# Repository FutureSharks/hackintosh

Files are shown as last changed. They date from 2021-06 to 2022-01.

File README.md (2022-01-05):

# My Hackintosh

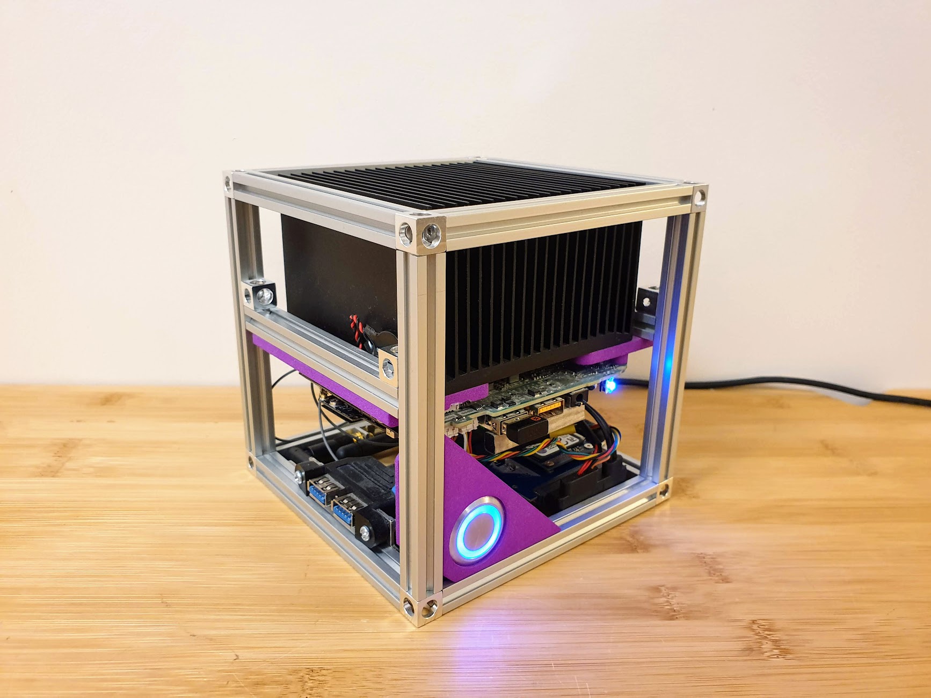
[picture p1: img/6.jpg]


My current build runs macOS Monterey 12.0.1, [OpenCore](https://dortania.github.io/OpenCore-Install-Guide/) 0.7.5 and is based on a fanless Intel [NUC8i5BEK](https://ark.intel.com/content/www/us/en/ark/products/126147/intel-nuc-kit-nuc8i5bek.html) with a [i5-8259U CPU](https://ark.intel.com/content/www/us/en/ark/products/135935/intel-core-i58259u-processor-6m-cache-up-to-3-80-ghz.html).

## What works, what does not

- ✅ GPU acceleration
- ✅ HDMI audio
- ✅ HDMI and USB-C video at 2560 x 1440 @ 60 Hz
- ✅ USB2 / USB3 / USB-C
- ✅ SATA storage
- ✅ WiFi/WLAN in M.2 slot
- ❔ Front panel audio: not tested
- ❔ SD card reader: not tested
- ❔ Other display resolutions: not tested
- ❌ Sleep/wake: Doesn't work
- ❌ Bluetooth: Unreliable (maybe antenna is inadequate)
- ❌ Built in WLAN/Bluetooth: It is [apparently possible but not perfect](https://github.com/OpenIntelWireless/itlwm)

## Hackintosh details

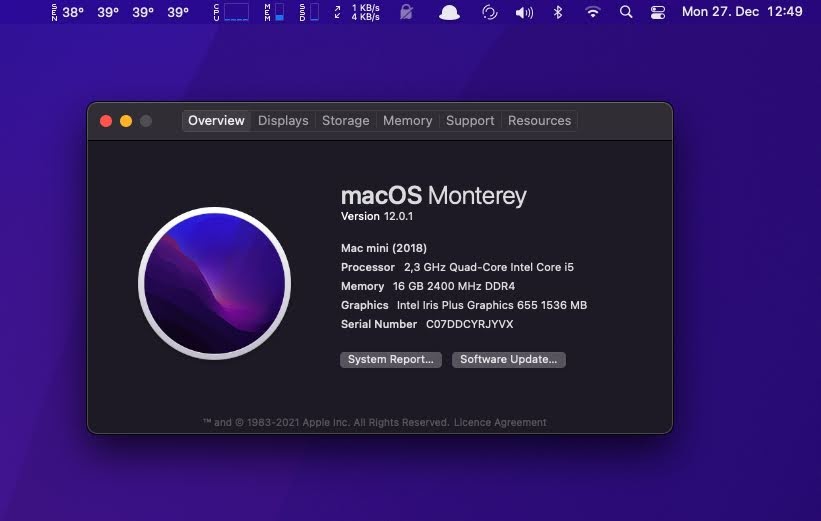
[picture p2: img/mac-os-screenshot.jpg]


Runs [OpenCore](https://dortania.github.io/OpenCore-Install-Guide/) 0.7.5:

- [config.plist](EFI/OC/config.plist)
- [EFI](EFI) directory

## Photos

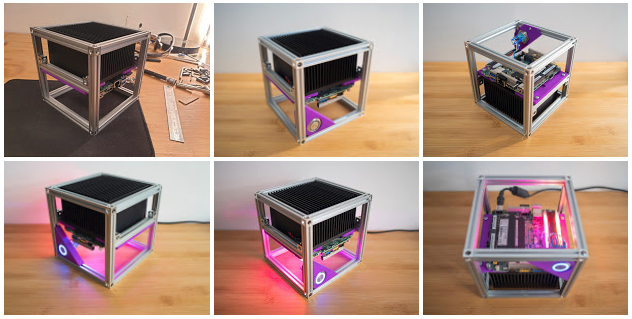
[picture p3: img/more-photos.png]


## Hardware

### Specs

- Intel Core i5-8259U CPU (built in)
- Intel Iris Plus Graphics 655 (built in)
- 16GB RAM F4-2400C16D-16G
- Kingston KC600 512GB mSATA SSD (with mSATA adapter)
- Broadcom BCM94360CD WiFi WLAN + Bluetooth 4.0 (with modified M.2 NGFF Adapter Card)
- Alpine AM4 Passive CPU cooler, required some machining to fit
- Makerbeam open case structure
- Custom 3D printed CPU mounting brackets
- Custom 3D printed power switch bracket

### Power consumption and temperatures

Power measured at wall, temperature measured from built in sensors.

| State | Power (watts) | CPU temp (°C) |
|---|---|---|
| Powered off | 0.5 | 0 |
| Booted OS, idle | 6-10 | 29 |
| Normal use with Chrome, AutoCAD, Spotify etc | 10-20 | 40-70 |
| Prime95 or stress | 52 | 90 |

### CAD files

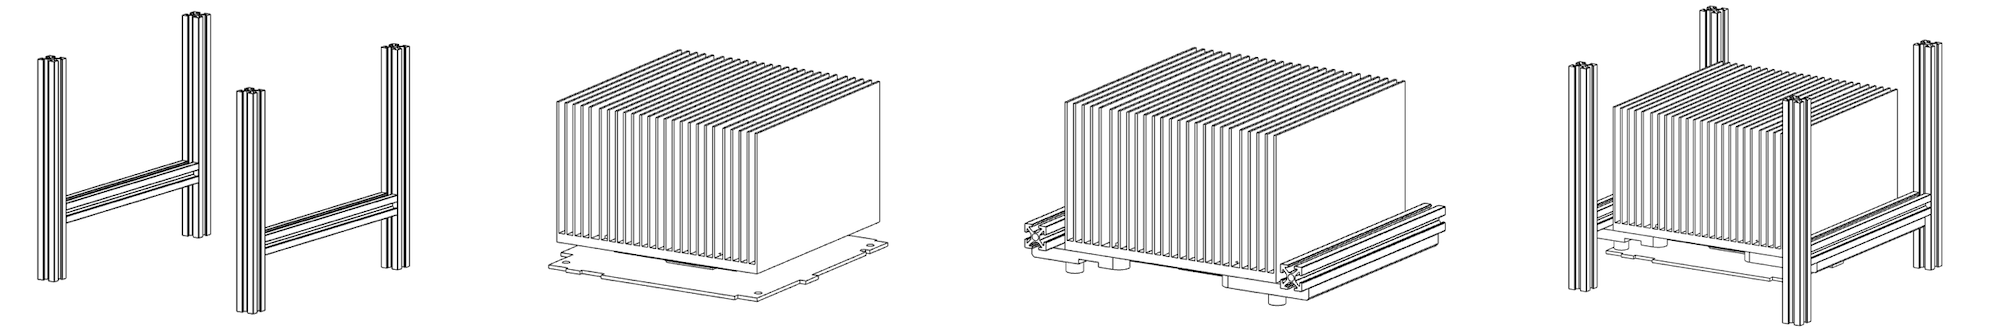
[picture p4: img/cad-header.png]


Fusion 360 project file, Heatsink bracket STL and Switch bracket STL files are in: [cad-files](cad-files)

## OpenCore setup process

Download OpenCore release and other required files:

```
# Save into separate directory
cd downloads

# Get Nucintosh release
wget https://github.com/zearp/Nucintosh/releases/download/v3.1/EFI_05112021.zip

# Get OpenCore release
wget https://github.com/acidanthera/OpenCorePkg/releases/download/0.7.5/OpenCore-0.7.5-RELEASE.zip

# Get others
wget https://github.com/acidanthera/OcBinaryData/raw/master/Drivers/HfsPlus.efi
wget https://github.com/acidanthera/VirtualSMC/releases/download/1.2.7/VirtualSMC-1.2.7-RELEASE.zip
wget https://github.com/acidanthera/Lilu/releases/download/1.5.7/Lilu-1.5.7-RELEASE.zip
wget https://github.com/acidanthera/WhateverGreen/releases/download/1.5.5/WhateverGreen-1.5.5-RELEASE.zip
wget https://github.com/acidanthera/AppleALC/releases/download/1.6.6/AppleALC-1.6.6-RELEASE.zip
wget https://github.com/acidanthera/IntelMausi/releases/download/1.0.7/IntelMausi-1.0.7-RELEASE.zip
wget https://github.com/acidanthera/BrcmPatchRAM/releases/download/2.6.1/BrcmPatchRAM-2.6.1-RELEASE.zip
wget https://github.com/acidanthera/NVMeFix/releases/download/1.0.9/NVMeFix-1.0.9-RELEASE.zip

# Get required SSDTs
wget https://github.com/dortania/Getting-Started-With-ACPI/raw/master/extra-files/compiled/SSDT-AWAC.aml
wget https://github.com/dortania/Getting-Started-With-ACPI/raw/master/extra-files/compiled/SSDT-PMC.aml
```

Extract all zip files in `downloads`.

Now build our initial EFI directory based on OpenCore release, [Nucintosh](https://github.com/zearp/Nucintosh) SSDTs and `config.plist`:

```
rm -rf EFI
cp -a downloads/OpenCore-0.7.5-RELEASE/X64/EFI .
```

Clean it up:

```
cp EFI/OC/Drivers/OpenRuntime.efi .
rm -f EFI/OC/Drivers/*
mv OpenRuntime.efi EFI/OC/Drivers/
cp EFI/OC/Tools/OpenShell.efi .
rm -f EFI/OC/Tools/*
mv OpenShell.efi EFI/OC/Tools/
```

Add other required files and kexts:

```
cp downloads/HfsPlus.efi EFI/OC/Drivers/
cp -a downloads/Lilu-1.5.7-RELEASE/Lilu.kext EFI/OC/Kexts/
cp -a downloads/VirtualSMC-1.2.7-RELEASE/Kexts/SMCProcessor.kext EFI/OC/Kexts/
cp -a downloads/VirtualSMC-1.2.7-RELEASE/Kexts/SMCSuperIO.kext EFI/OC/Kexts/
cp -a downloads/VirtualSMC-1.2.7-RELEASE/Kexts/VirtualSMC.kext EFI/OC/Kexts/
cp -a downloads/WhateverGreen-1.5.5-RELEASE/WhateverGreen.kext EFI/OC/Kexts/
cp -a downloads/AppleALC-1.6.6-RELEASE/AppleALC.kext EFI/OC/Kexts/
cp -a downloads/IntelMausi-1.0.7-RELEASE/IntelMausi.kext EFI/OC/Kexts/
cp -a downloads/BrcmPatchRAM-2.6.1-RELEASE/BlueToolFixup.kext EFI/OC/Kexts/
```

Get `config.plist`, SSDTs and USBPorts kext from [Nucintosh](https://github.com/zearp/Nucintosh) release:

```
cp downloads/EFI/OC/config.plist EFI/OC/config.plist
cp downloads/EFI/OC/ACPI/*.aml EFI/OC/ACPI/
cp -a downloads/EFI/OC/Kexts/USBPorts.kext EFI/OC/Kexts/
```

Add SSDTs:

```
cp downloads/*.aml EFI/OC/ACPI/
```

Then make some manual changes to `config.plist`:

- Remove `IntelBluetooth`
- Remove `cpufriend`

Edit `config.plist` with [GenSMBIOS](https://github.com/corpnewt/GenSMBIOS) to update the fields:

- MLB
- ROM
- SystemSerialNumber
- SystemUUID

Now copy [EFI](EFI) directory to your USB drive and install macOS Monterey:

## Bios settings

Update to the latest (0089) BIOS. Go into BIOS settings and:

1. Load BIOS defaults (F9)
2. Go to advanced settings
3. Devices -> USB:
  - Portable Device Charging Mode: OFF
  - USB Legacy: Uncheck
4. Devices -> Onboard Devices:
  - WLAN: Uncheck
  - Bluetooth: Uncheck
4. Devices -> Legacy Device Configuration -> HDMI CEC Control: Uncheck
5. Security -> Thunderbolt Security Level: Legacy Mode
6. Power:
  - Wake on LAN from S4/S5: Stay Off
  - Max Performance Enabled: Uncheck
  - Intel Dynamic Power Technology: Energy Efficient Performance
  - Color: Violet
7. Boot:
  - Boot Configuration -> Network Boot: Disable
  - Secure Boot: Uncheck

## Credits

- https://github.com/zearp/Nucintosh

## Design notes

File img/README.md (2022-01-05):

# Photos

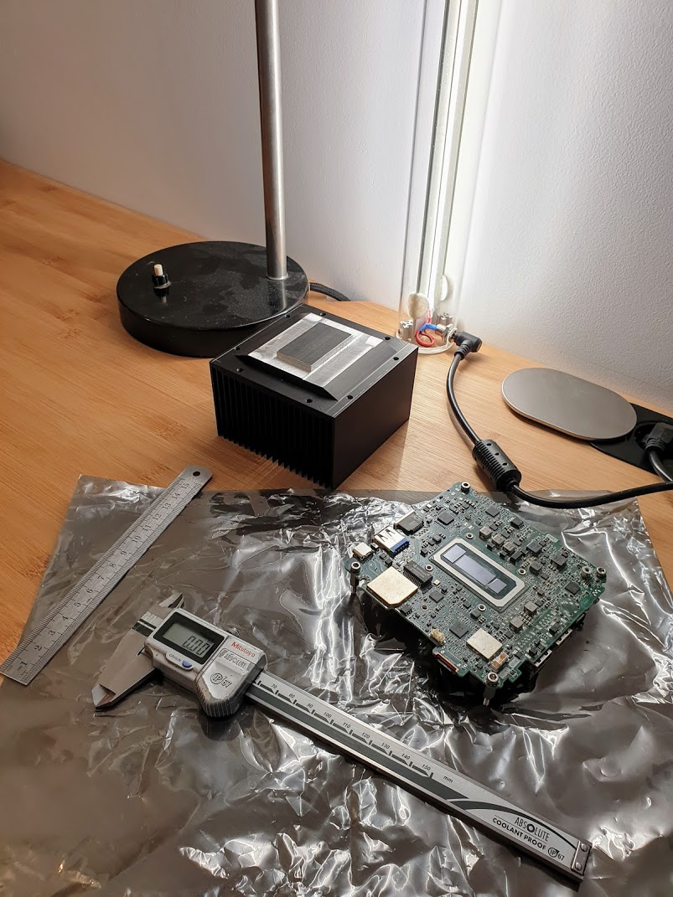
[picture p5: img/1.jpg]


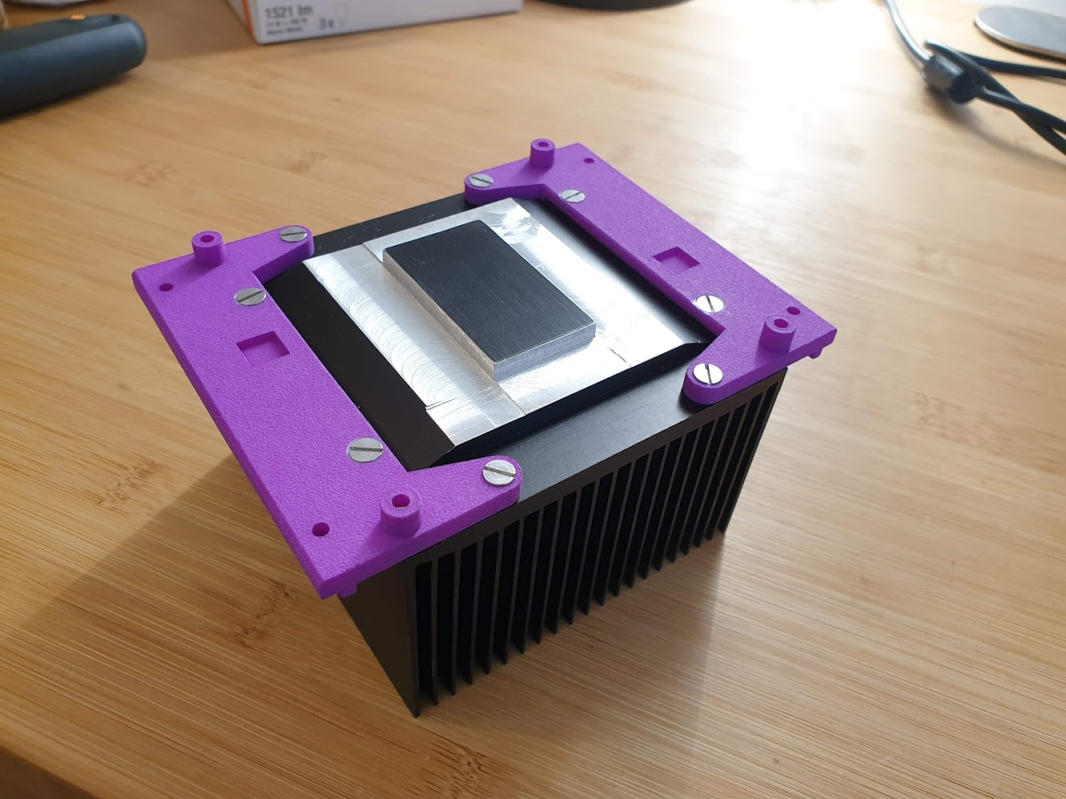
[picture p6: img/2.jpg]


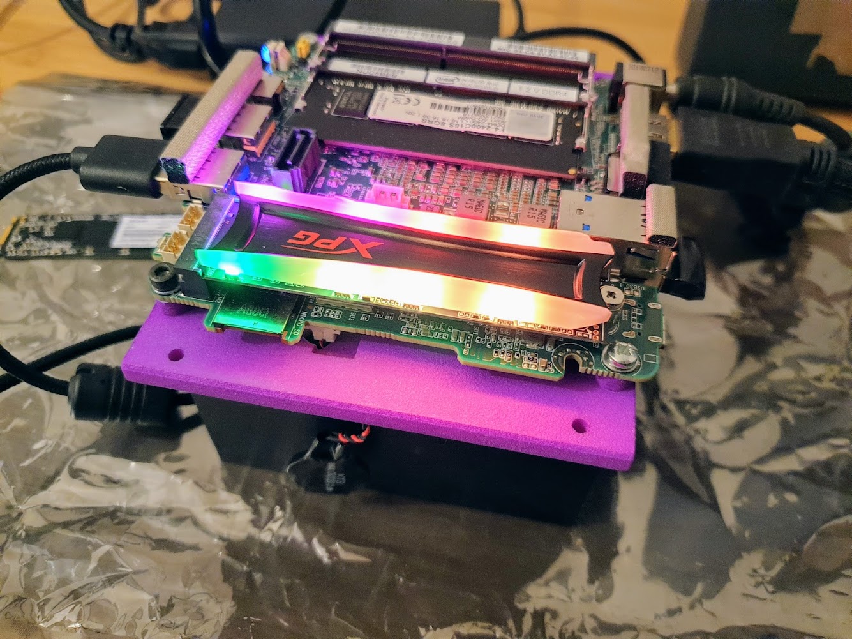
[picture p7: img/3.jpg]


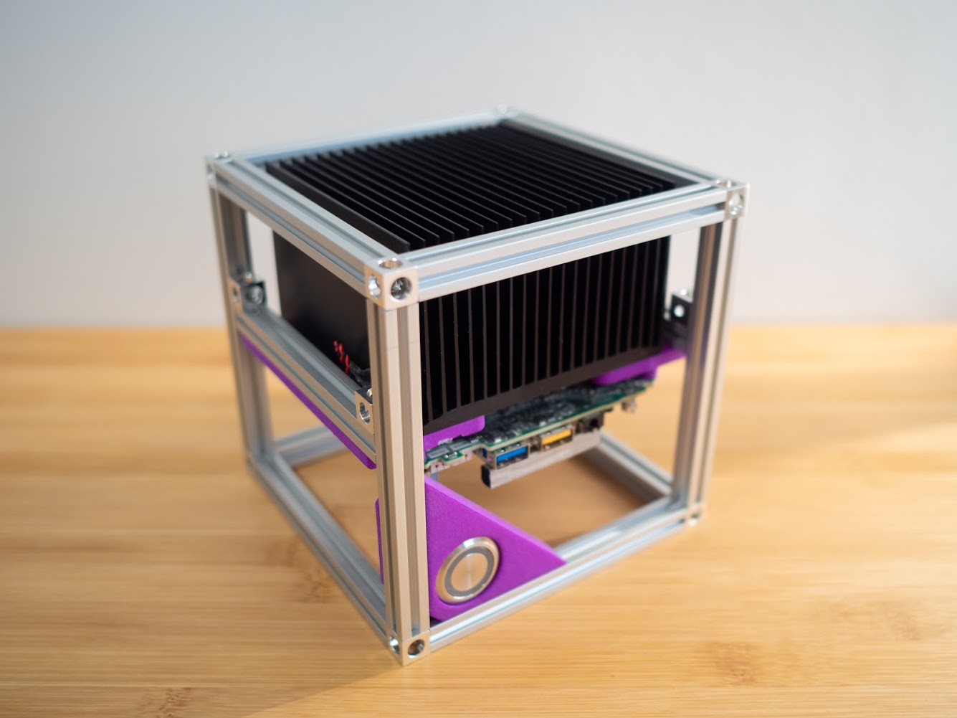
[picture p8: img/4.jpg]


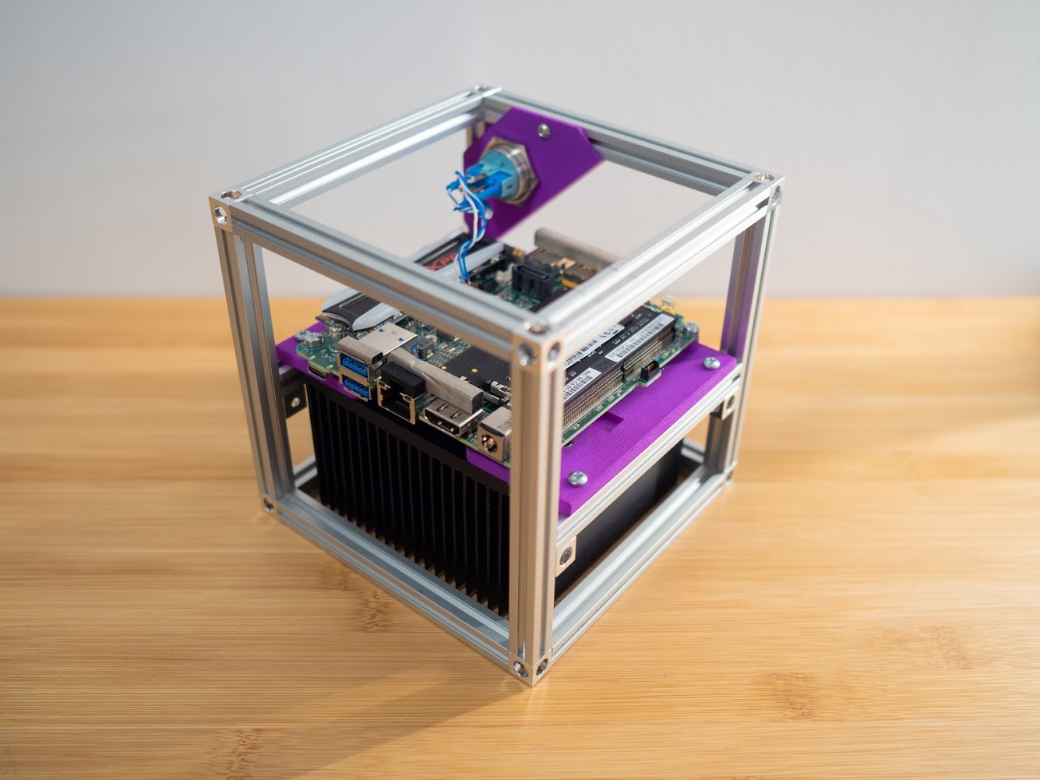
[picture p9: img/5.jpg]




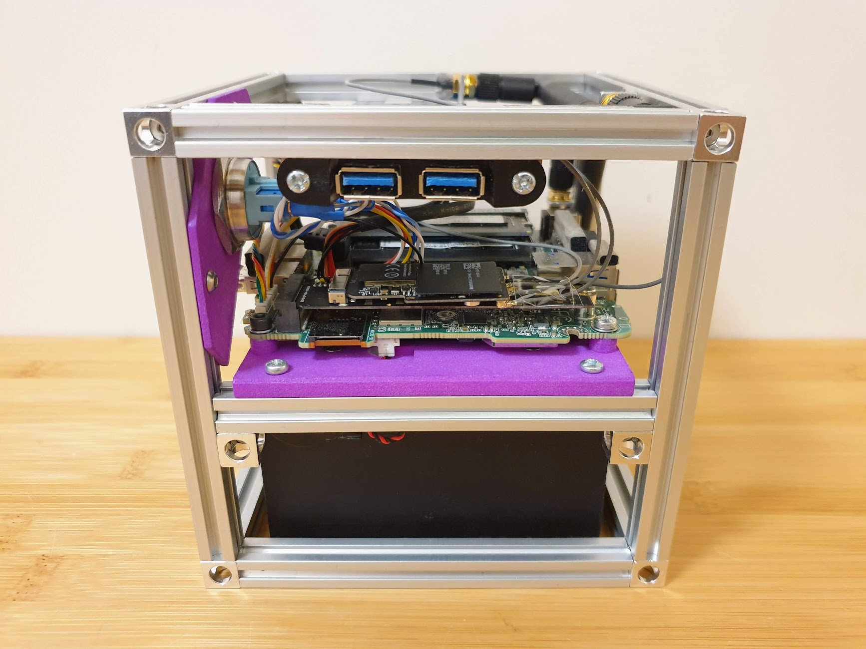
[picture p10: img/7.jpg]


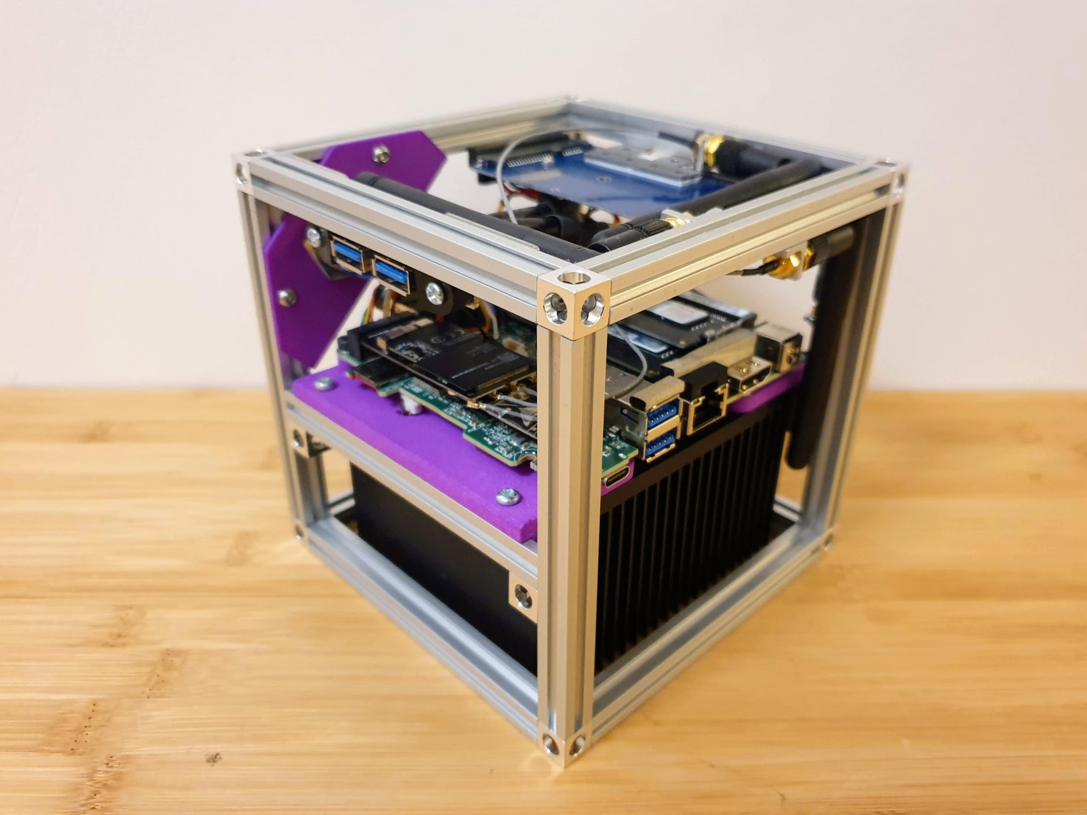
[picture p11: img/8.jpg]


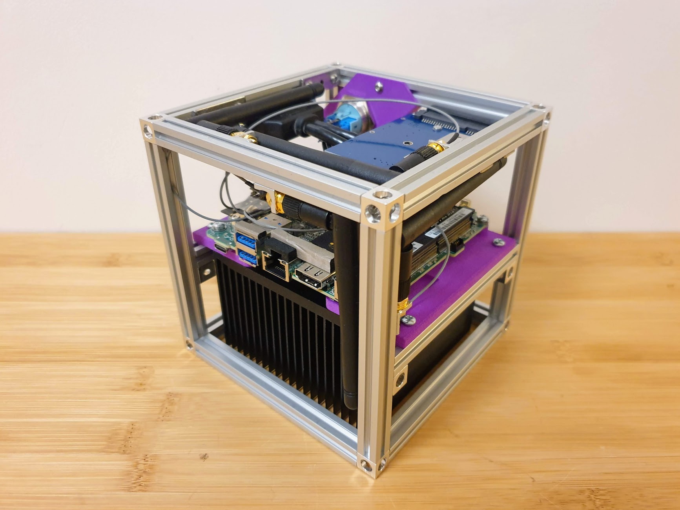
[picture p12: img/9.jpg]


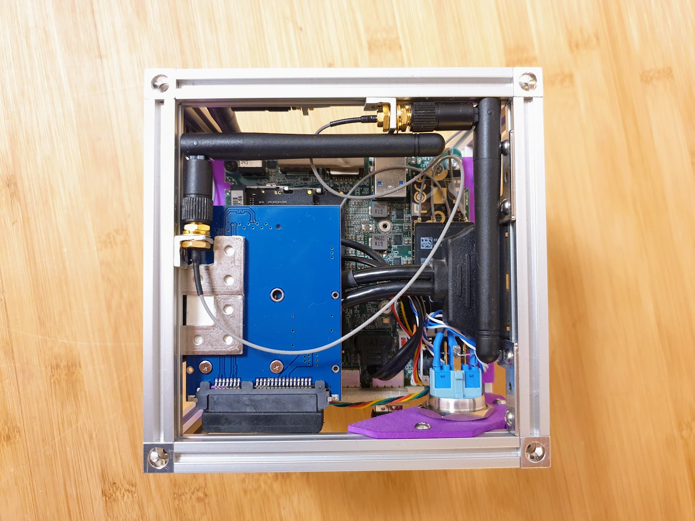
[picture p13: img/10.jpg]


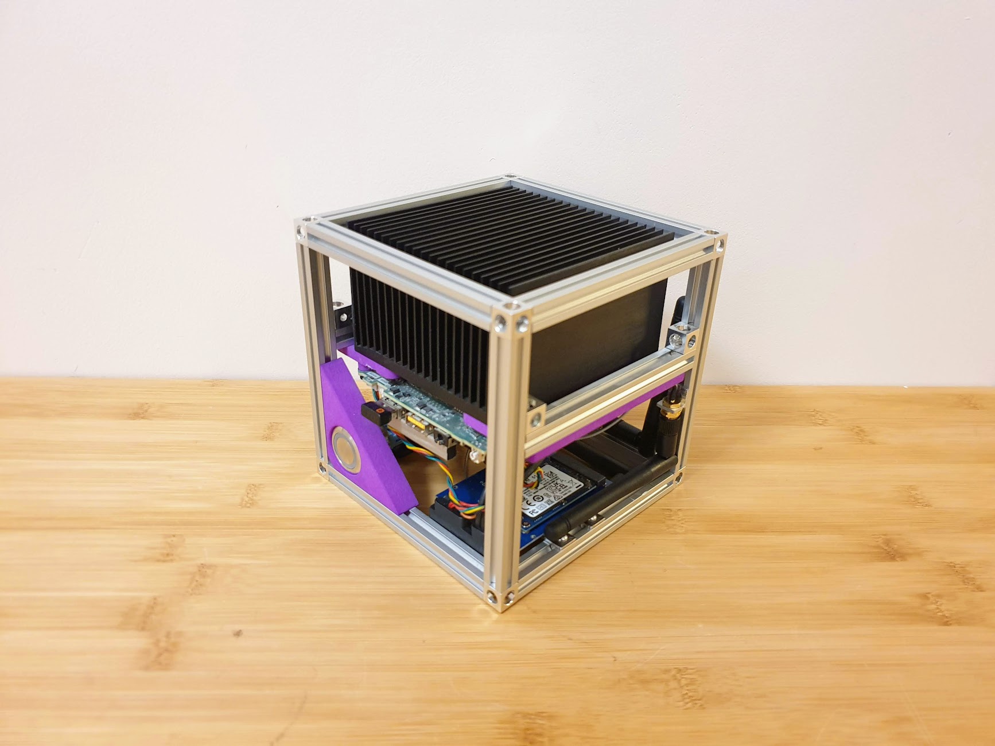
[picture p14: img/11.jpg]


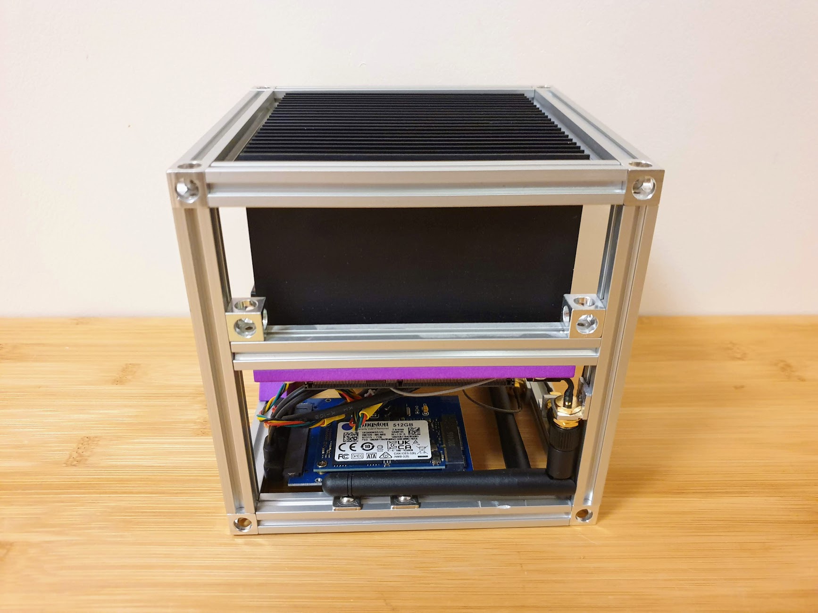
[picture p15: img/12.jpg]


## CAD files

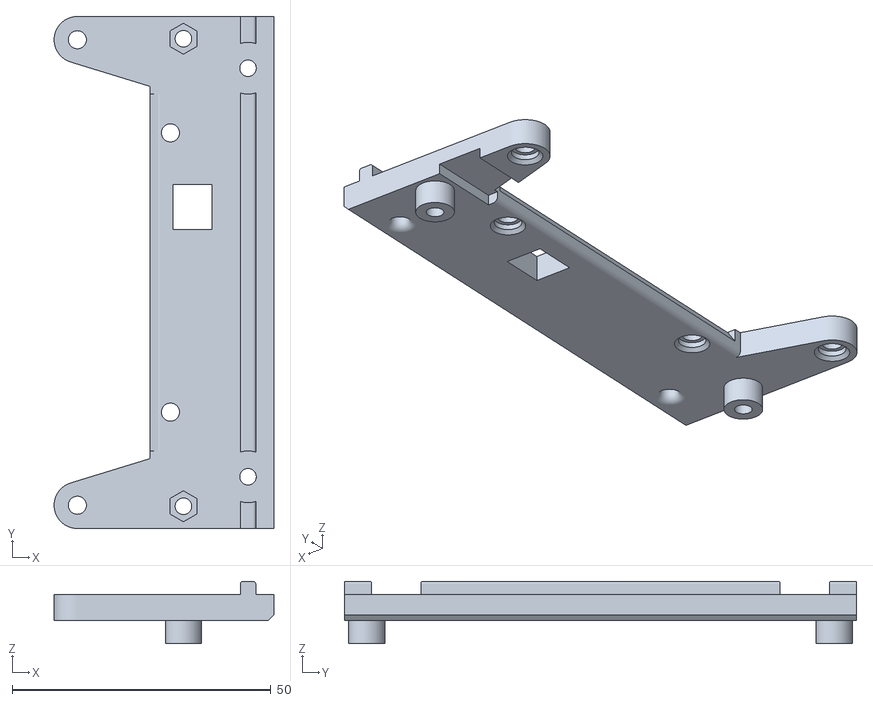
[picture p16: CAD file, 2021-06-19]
cad-files/heatsink-bracket.stl
42.5 x 99.0 x 12.0

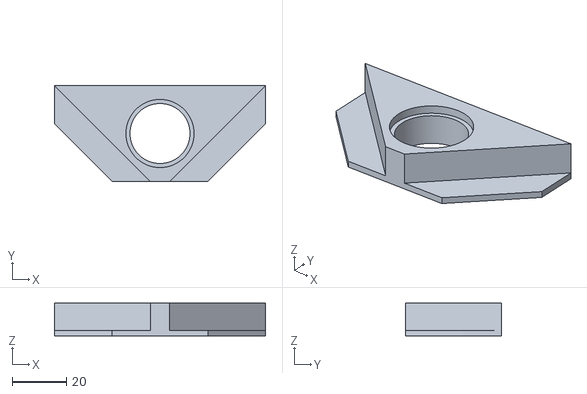
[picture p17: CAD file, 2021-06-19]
cad-files/switch-bracket.stl
77.8 x 35.4 x 12.0

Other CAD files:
cad-files/fusion-360-design.f3d
